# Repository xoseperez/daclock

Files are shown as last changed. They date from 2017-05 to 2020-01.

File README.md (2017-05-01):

# DA CLOCK

This repository contains the schematics and board layouts for Eagle of the different DaClock versions I've done so far.
The common parts between all these versions are: a microcontroller on board with some power management, an RTC and connectors for LED strips or matrices.

Current version is 3.0, based on ESP8266 and DS1337S, also features a buzzer and support for both WS2812 strips/matrices and 5050 "single color" strips.

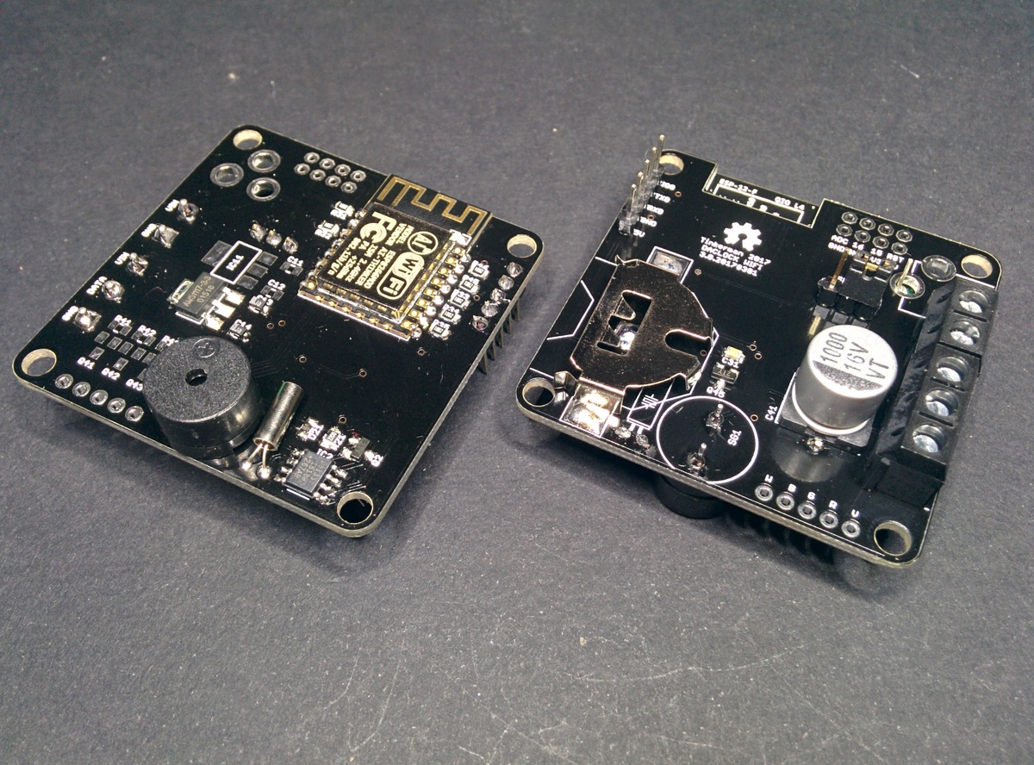
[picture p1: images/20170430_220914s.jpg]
DaClock 3.0


## Versions

### Version 3.0 - WIFI LITE

This is the latest version of the DA CLOCK board, a custom ESP8266-based clock with an RTC, a buzzer and output to handle WS2812 strips.

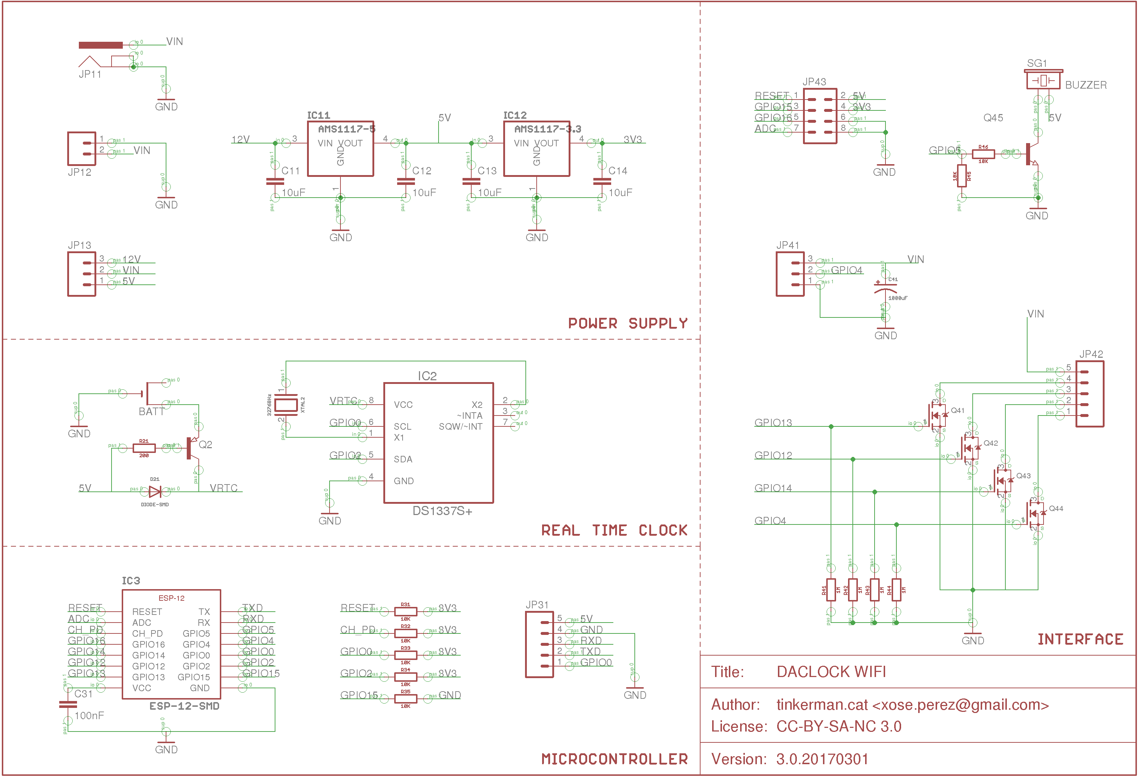
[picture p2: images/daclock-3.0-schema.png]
DaClock 3.0 - schema


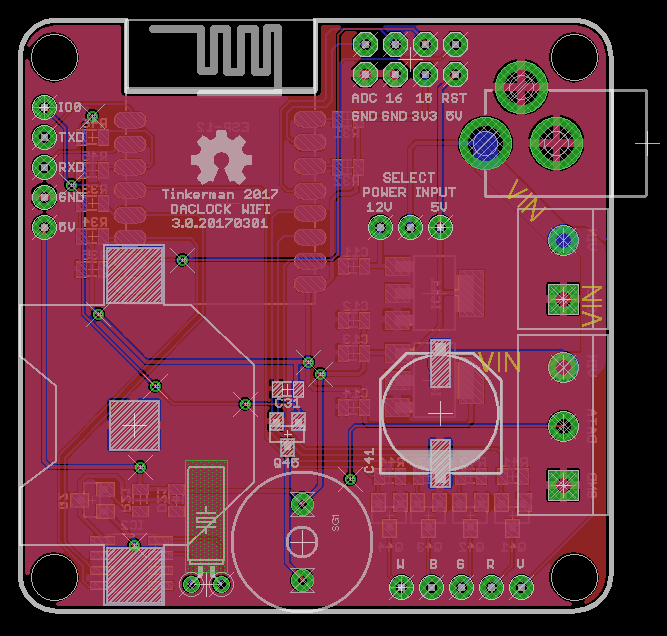
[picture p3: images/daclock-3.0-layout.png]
DaClock 3.0 - layout


#### Bill of materials for a WS2812-based clock

|Item|Buy|Quantity|CPU <sup>units</sup>|Total|
|---|---|---|---|---|
|Tinkerman Da Clock WIFI 3.0|[OSH Park](https://oshpark.com/shared_projects/gDLQyM9I)|1|6.57€ <sup>3</sup>|6.57€|
|Ai-Thinker ESP12F|[Aliexpress](http://s.click.aliexpress.com/e/mUZjemI) / [Ebay](https://rover.ebay.com/rover/1/711-53200-19255-0/1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)|1|2.10€ <sup>5</sup>|2.10€|
|AMS1117-3.3|[Aliexpress](http://s.click.aliexpress.com/e/uj6iuNv) / [Ebay](https://rover.ebay.com/rover/1/711-53200-19255-0/1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)|1|0.03€ <sup>50</sup>|0.03€|
|DS1337S|[Aliexpress](http://s.click.aliexpress.com/e/qbaAUr3) / [Ebay](https://rover.ebay.com/rover/1/711-53200-19255-0/1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)|1|0.62€ <sup>10</sup>|0.62€|
|32KHz crystal|[Aliexpress](http://s.click.aliexpress.com/e/UVrrFmU) / [Ebay](https://rover.ebay.com/rover/1/711-53200-19255-0/1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)|1|0.03€ <sup>50</sup>|0.03€|
|1N4148 SMD Diode|[Aliexpress](http://s.click.aliexpress.com/e/i2nayrB)|1|0.14€ <sup>10</sup>|0.14€|
|Buzzer|[Aliexpress](http://s.click.aliexpress.com/e/VbeAu3z) / [Ebay](https://rover.ebay.com/rover/1/711-53200-19255-0/1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)|1|0.15€<sup>10</sup>|0.15€|
|S8550 SMD NPN transistor|[Aliexpress](http://s.click.aliexpress.com/e/VZ3FYN7)|2|0.02€<sup>100</sup>|0.04€|
|100nF 0805 ceramic capacitor||1|0.01€ <sup>100</sup>|0.01€|
|1uF 10V 0805 tantalum capacitor|[Aliexpress](http://s.click.aliexpress.com/e/ey3ZVn2)|2|0.06€ <sup>50</sup>|0.12€|
|1000uF 16V electrolytic SMD capacitor|[Aliexpress](http://s.click.aliexpress.com/e/MjQ7eMf)|1|0.19€ <sup>10</sup>|0.19€|
|200Ohm 0805 resistor||1|0.01€ <sup>100</sup>|0.01€|
|10KOhm 0805 resistor||7|0.01€ <sup>100</sup>|0.07€|
|2 positions 5mm screw terminal|[Aliexpress](http://s.click.aliexpress.com/e/a2fqnM7)|1|0.06€ <sup>100</sup>|0.06€|
|3 positions 5mm screw terminal|[Aliexpress](http://s.click.aliexpress.com/e/Vjaa2RB)|1|0.07€ <sup>100</sup>|0.07€|
|3 position male header||1|0.01€ <sup>100</sup>|0.01€|
|5 position male header||1|0.01€ <sup>100</sup>|0.01€|
|Jumper||1|0.01€ <sup>100</sup>|0.01€|
|**Total**||||10.25€|

* (units) Minimum quantity for the stated price.
* Prices are based on the cheapest option, usually Aliexpress.
* Check the schematic (image or eagle file) for relation between parts and values.

### Version 2.1 - WIFI

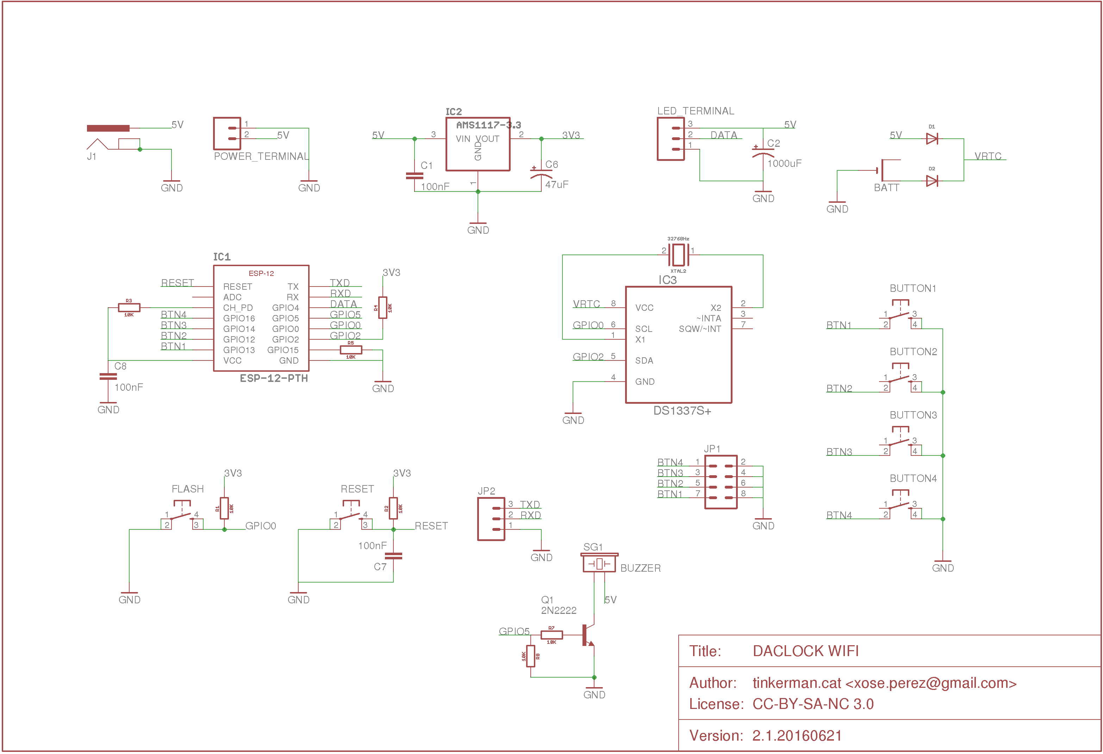
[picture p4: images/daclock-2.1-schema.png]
DaClock 2.1 - schema


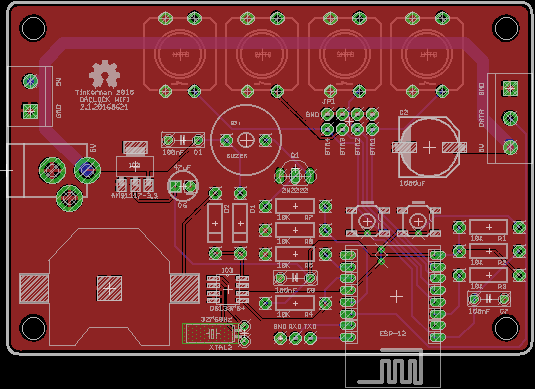
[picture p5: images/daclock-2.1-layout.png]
DaClock 2.1 - layout


### Version 1.2

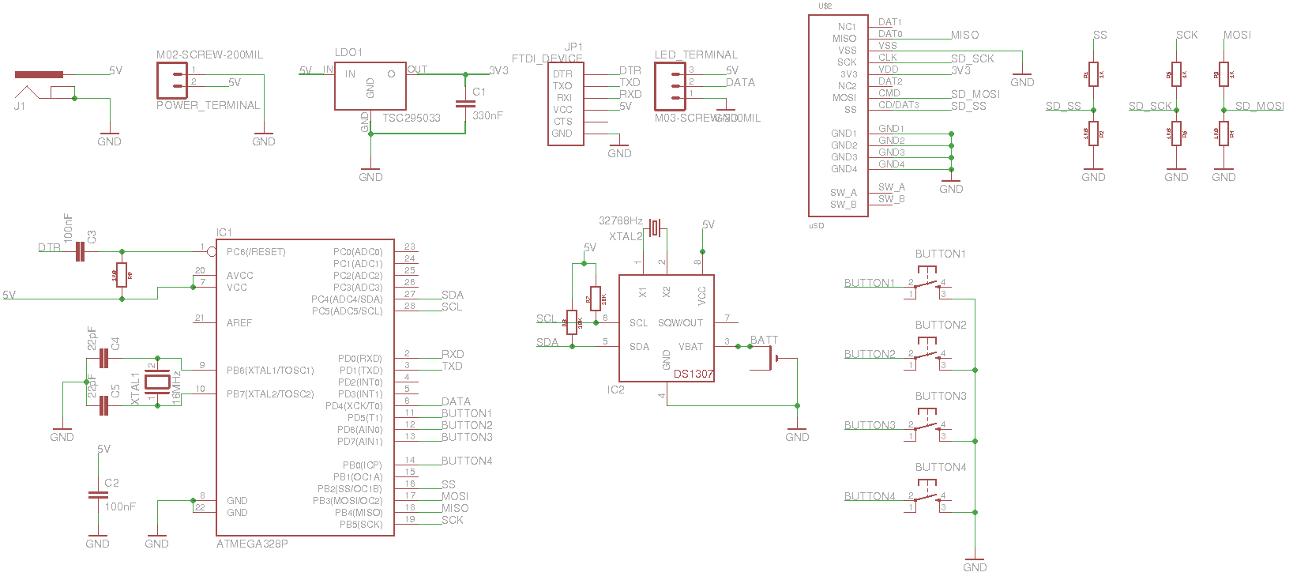
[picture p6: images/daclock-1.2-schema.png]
DaClock 1.2 - schema


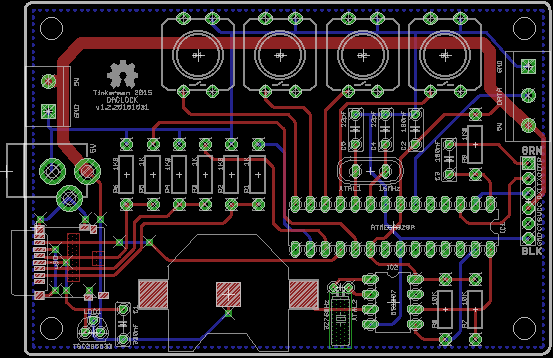
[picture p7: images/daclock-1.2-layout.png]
DaClock 1.2 - layout


## Firmware

* Project [Wordclock](https://bitbucket.org/xoseperez/wordclock) uses version 1.0 of this board (atmega328p based).
- Project [Slices](http://github.com/xoseperez/slices) uses version 3.0 of this board (ESP8266 based).

## Open Hardware

Hardware designs (schematics and CAD) files are licensed under the [Creative Commons Attribution-ShareAlike 3.0 Unported License](http://creativecommons.org/licenses/by-sa/3.0/) and follow the terms of the [OSHW (Open-source hardware) Statement of Principles 1.0.](http://freedomdefined.org/OSHW)

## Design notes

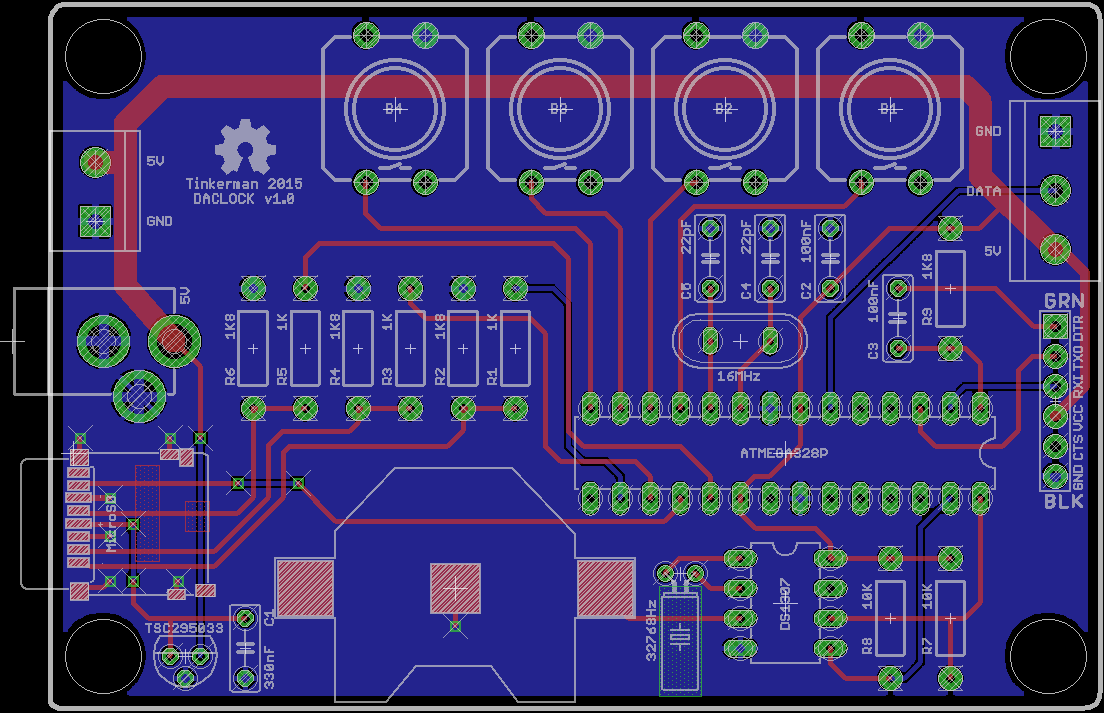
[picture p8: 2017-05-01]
images/daclock-1.0-layout.png

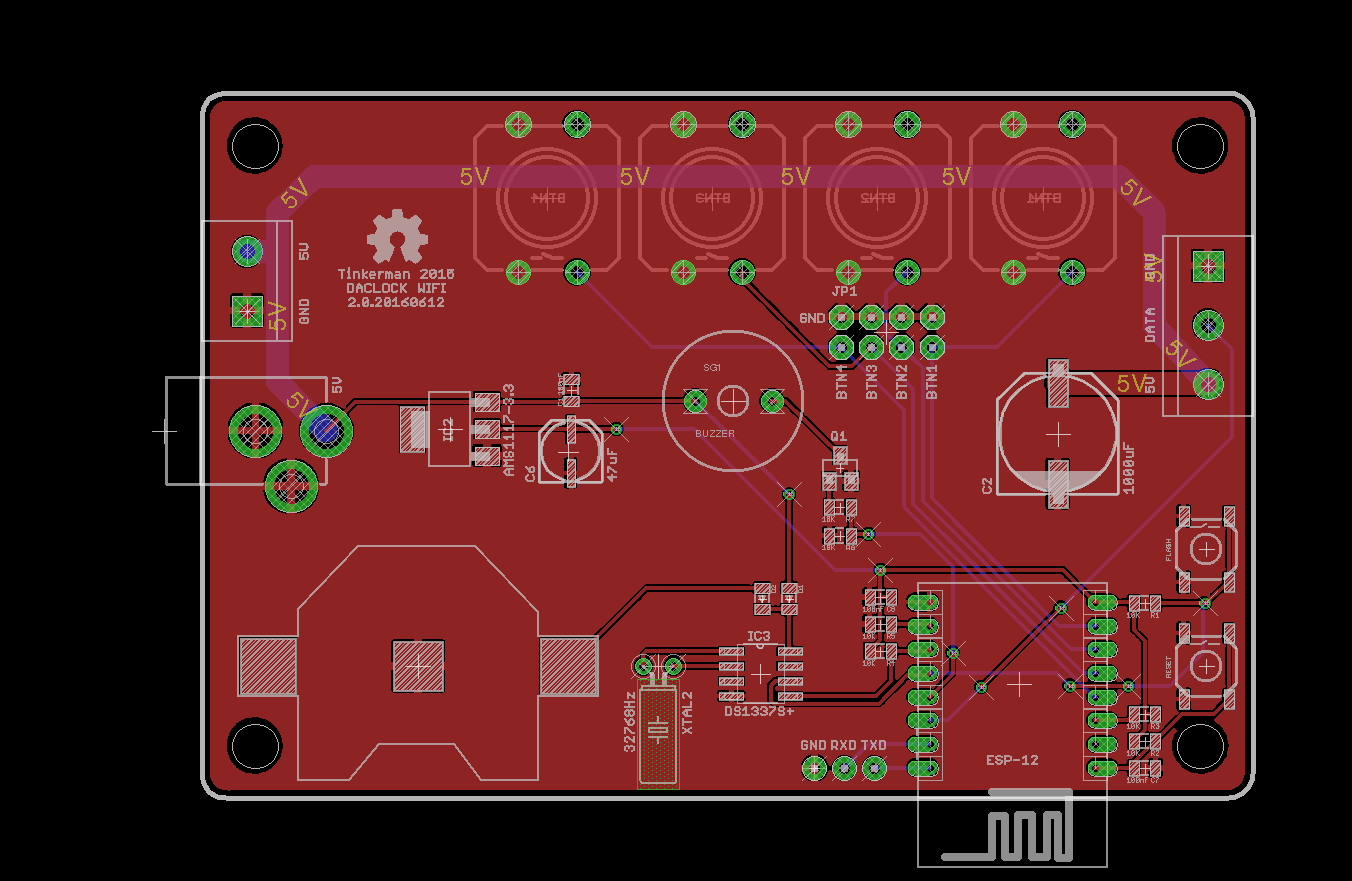
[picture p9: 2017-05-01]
images/daclock-2.0-layout.png

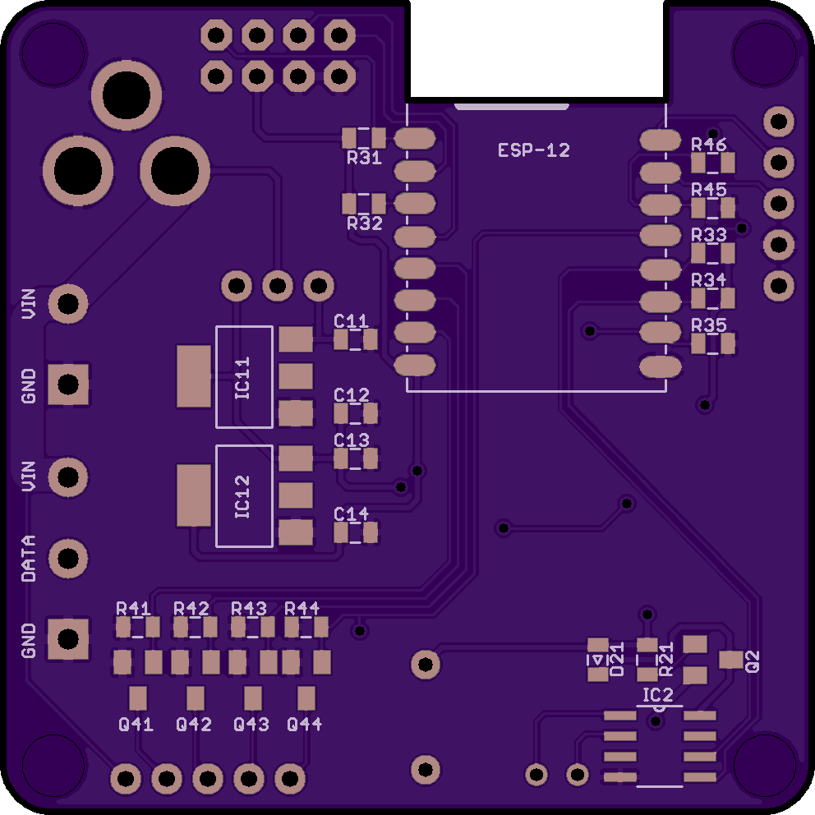
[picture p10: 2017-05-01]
images/daclock-3.0-render-bottom.png

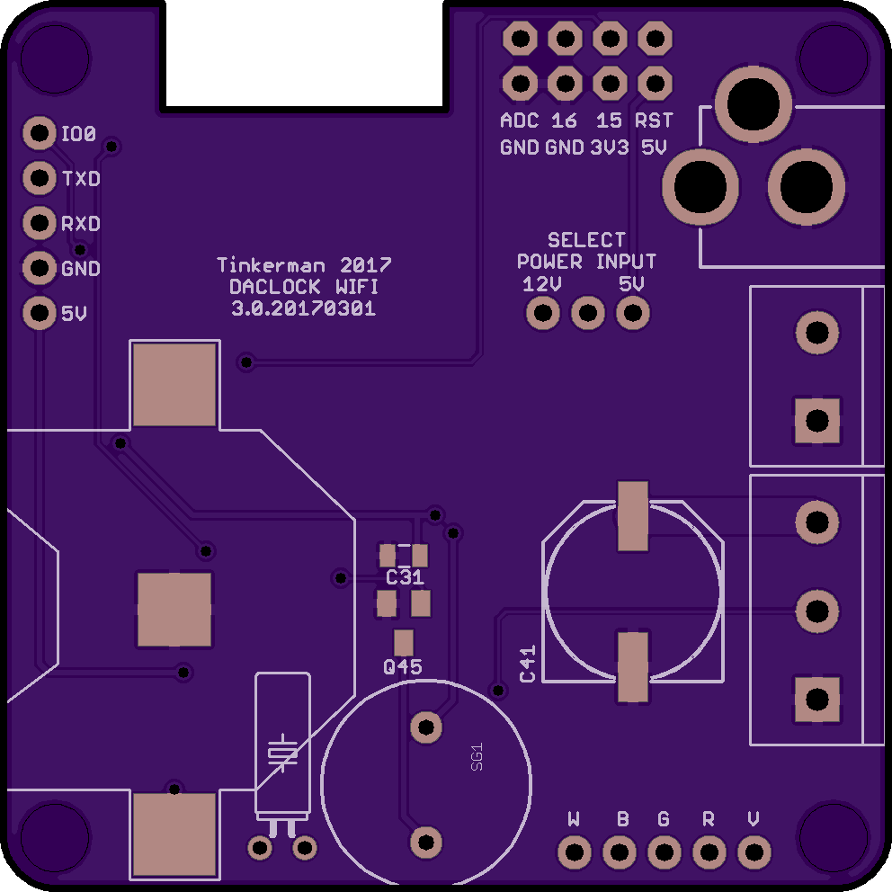
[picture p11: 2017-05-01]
images/daclock-3.0-render-top.png

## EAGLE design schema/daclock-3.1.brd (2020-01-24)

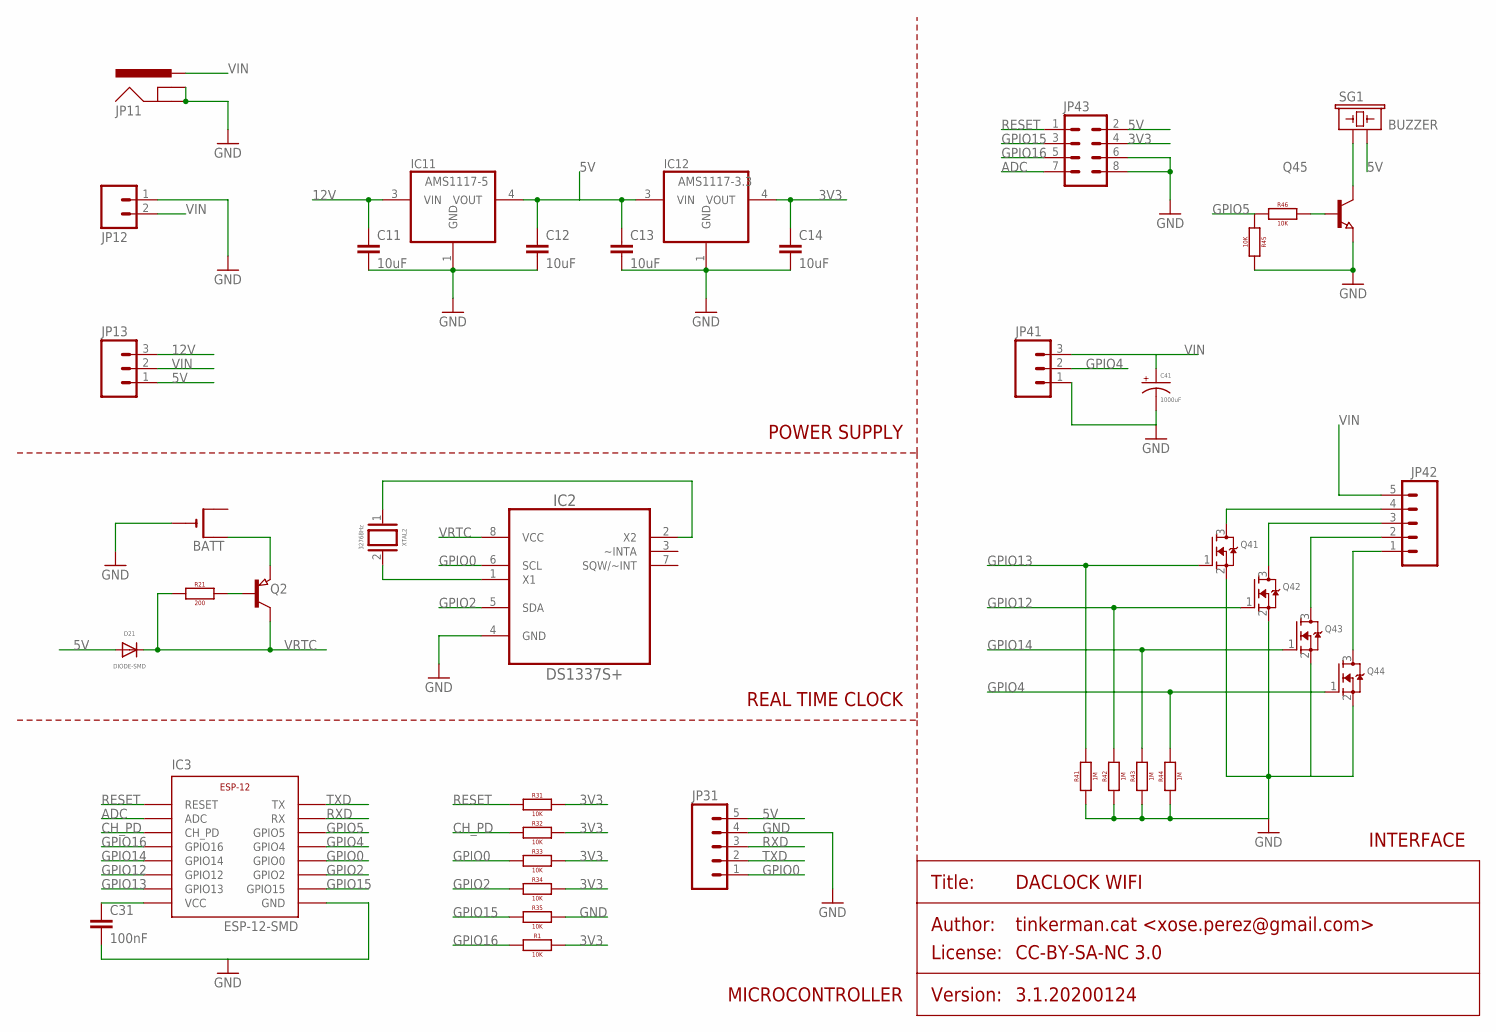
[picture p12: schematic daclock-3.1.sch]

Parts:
BATT: CR2032SMT; CR2032-SMD
C11, C12, C13, C14: 10uF; 0805
C31: 100nF; 0805
C41: 1000uF; PANASONIC_G
D21: DIODE-SMD; 0805_DIODE
IC2: DS1337S+; SOIC127P600X175-8N
IC3: ESP-12-SMD
IC11: AMS1117-5; SOT223
IC12: AMS1117-3.3; SOT223
JP11: POWER_JACKPTH; POWER_JACK_PTH
JP12: M02200MIL; SCREWTERMINAL-200MIL-2
JP13: M03PTH; 1X03
JP31, JP42: M05NO_SILK; 1X05_NO_SILK
JP41: M03200MIL; SCREWTERMINAL-200MIL-3
JP43: M04X2; 2X4
Q2: PNP-TRANSISTOR_SOT23; SOT23
Q41, Q42, Q43, Q44: MOSFET-NREFLOW; SOT23
Q45: NPN-TRANSISTOR_SOT23; SOT23
R1, R31, R32, R33, R34, R35, R45, R46: 10K; 0805
R21: 200; 0805
R41, R42, R43, R44: 1M; 0805
SG1: BUZZER; BUZZER-12MM
XTAL2: 32768Hz; TC38H

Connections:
3V3: C14.1, C31.1, IC3.VCC, IC12.4 (VOUT), JP43.4, R1.2, R31.2, R32.2, R33.2, R34.2
5V: C12.1, C13.1, D21.A, IC11.4 (VOUT), IC12.3 (VIN), JP13.1, JP31.5, JP43.2, SG1.- (2)
12V: C11.1, IC11.3 (VIN), JP13.3
ADC: IC3.ADC, JP43.7
CH_PD: IC3.CH_PD, R32.1
GND: BATT.-, C11.2, C12.2, C13.2, C14.2, C31.2, C41.-, IC2.4 (GND), IC3.GND, IC11.1 (GND), IC12.1 (GND), JP11.GND, JP11.GNDBREAK, JP12.1, JP31.4, JP41.1, JP43.6, JP43.8, Q41.2 (S), Q42.2 (S), Q43.2 (S), Q44.2 (S), Q45.2 (E), R35.2, R41.1, R42.1, R43.1, R44.1, R45.2
GPIO0: IC2.6 (SCL), IC3.GPIO0, JP31.1, R33.1
GPIO2: IC2.5 (SDA), IC3.GPIO2, R34.1
GPIO4: IC3.GPIO4, JP41.2, Q44.1 (G), R44.2
GPIO5: IC3.GPIO5, R45.1, R46.1
GPIO12: IC3.GPIO12, Q42.1 (G), R42.2
GPIO13: IC3.GPIO13, Q41.1 (G), R41.2
GPIO14: IC3.GPIO14, Q43.1 (G), R43.2
GPIO15: IC3.GPIO15, JP43.3, R35.1
GPIO16: IC3.GPIO16, JP43.5, R1.1
unnamed: Q45.1 (B), R46.2
unnamed: IC2.1 (X1), XTAL2.2
unnamed: IC2.2 (X2), XTAL2.1
unnamed: JP42.4, Q41.3 (D)
unnamed: Q2.1 (B), R21.2
unnamed: JP42.3, Q42.3 (D)
unnamed: BATT.+$1 (+), Q2.2 (E)
unnamed: JP42.2, Q43.3 (D)
unnamed: JP42.1, Q44.3 (D)
unnamed: Q45.3 (C), SG1.+ (1)
RESET: IC3.RESET, JP43.1, R31.1
RXD: IC3.RX, JP31.3
TXD: IC3.TX, JP31.2
VIN: C41.+, JP11.PWR, JP12.2, JP13.2, JP41.3, JP42.5
VRTC: D21.C, IC2.8 (VCC), Q2.3 (C), R21.1

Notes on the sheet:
POWER SUPPLY
REAL TIME CLOCK
MICROCONTROLLER
INTERFACE

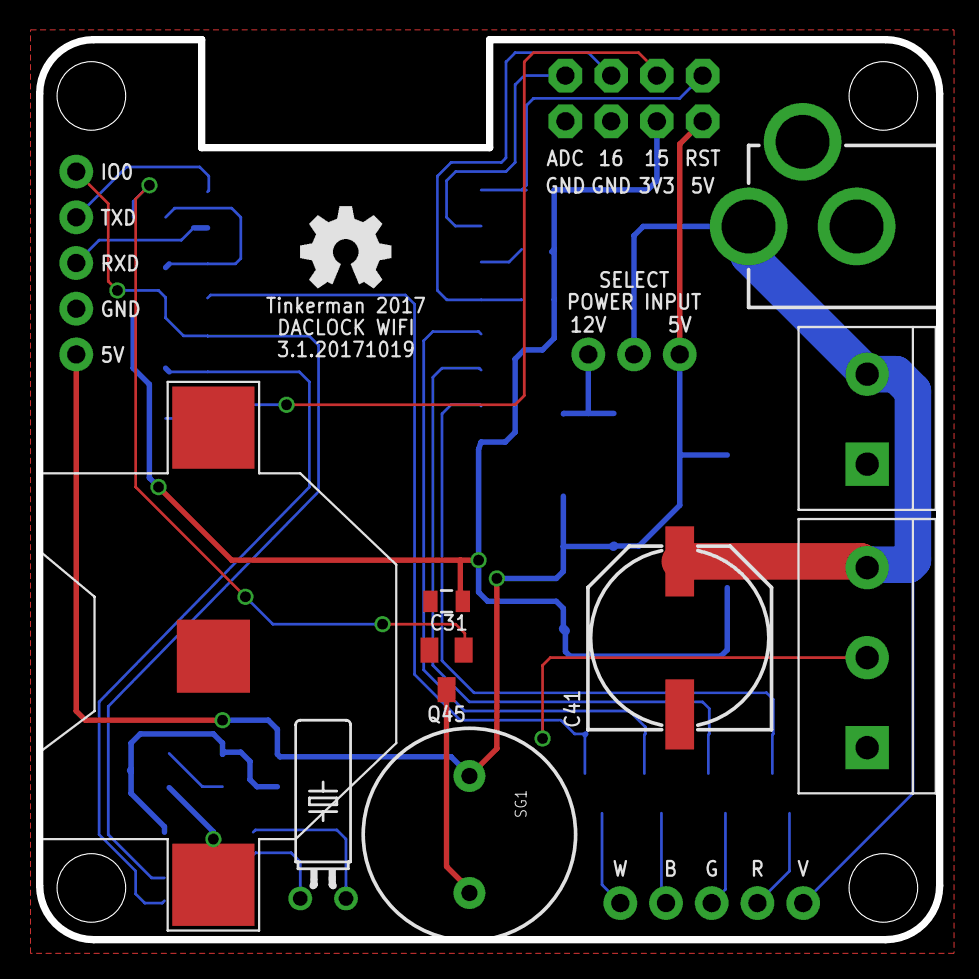
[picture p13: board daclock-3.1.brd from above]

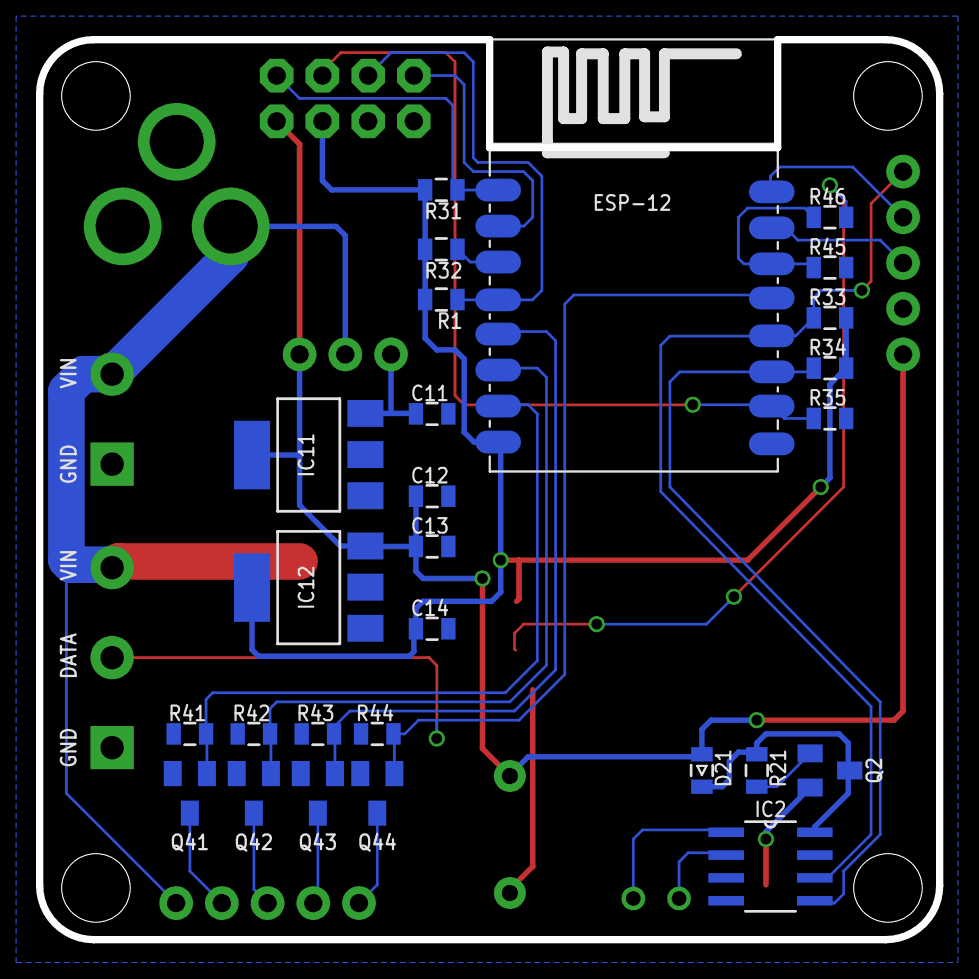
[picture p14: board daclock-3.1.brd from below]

Board: 2 copper layers, 50.0 x 50.0 mm, 40 parts (27 on the bottom side), 30 nets.

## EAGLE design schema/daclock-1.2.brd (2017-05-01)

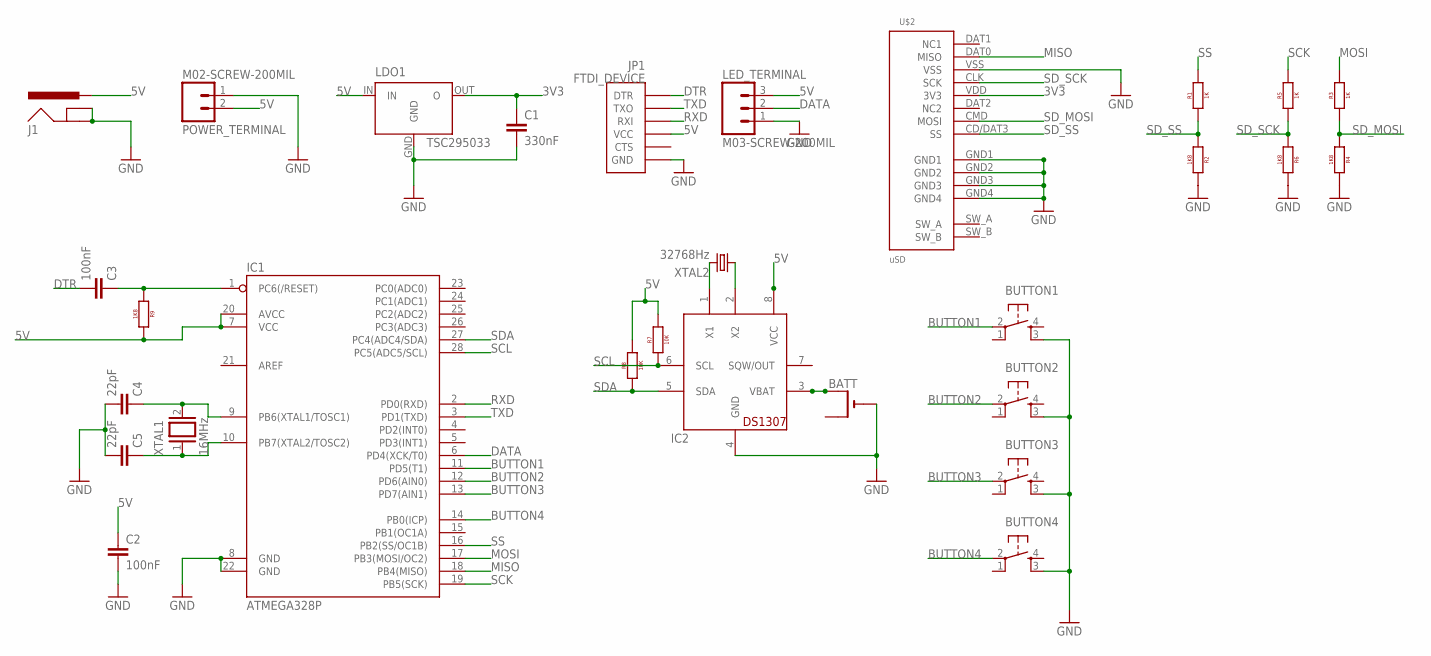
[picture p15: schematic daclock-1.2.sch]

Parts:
BATT: CR2032SMT; CR2032-SMD
BUTTON1: B1; TACTILE_BUTTON
BUTTON2: B2; TACTILE_BUTTON
BUTTON3: B3; TACTILE_BUTTON
BUTTON4: B4; TACTILE_BUTTON
C1: 330nF; C050-025X075
C2, C3: 100nF; C050-025X075
C4, C5: 22pF; C050-025X075
IC1: ATMEGA328P; DIL28-3
IC2: DS1307; DIL08
J1: POWER_JACKPTH; POWER_JACK_PTH
JP1: FTDI_DEVICE; FTDI_DEVICE_SIDE
LDO1: TSC295033; TO92
LED_TERMINAL: M03-SCREW-200MIL; SCREWTERMINAL-200MIL-3
POWER_TERMINAL: M02-SCREW-200MIL; SCREWTERMINAL-200MIL-2
R1, R3, R5: 1K; AXIAL-0.4
R2, R4, R6, R9: 1K8; AXIAL-0.4
R7, R8: 10K; AXIAL-0.4
U$2: uSD; DM3D
XTAL1: 16MHz; QS
XTAL2: 32768Hz; TC38H

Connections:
3V3: C1.1, LDO1.OUT (O), U$2.VDD (3V3)
5V: C2.1, IC1.7 (VCC), IC1.20 (AVCC), IC2.8 (VCC), J1.PWR, JP1.P$4 (VCC), LDO1.IN, LED_TERMINAL.3, POWER_TERMINAL.2, R7.P$2 (2), R8.P$2 (2), R9.P$2 (2)
BUTTON1: BUTTON1.2 (SWA1), IC1.11 (PD5(T1))
BUTTON2: BUTTON2.2 (SWA1), IC1.12 (PD6(AIN0))
BUTTON3: BUTTON3.2 (SWA1), IC1.13 (PD7(AIN1))
BUTTON4: BUTTON4.2 (SWA1), IC1.14 (PB0(ICP))
DATA: IC1.6 (PD4(XCK/T0)), LED_TERMINAL.2
DTR: C3.2, JP1.P$1 (DTR)
GND: BATT.-, BUTTON1.3 (SWB2), BUTTON2.3 (SWB2), BUTTON3.3 (SWB2), BUTTON4.3 (SWB2), C1.2, C2.2, C4.2, C5.2, IC1.8 (GND), IC1.22 (GND), IC2.4 (GND), J1.GND, J1.GNDBREAK, JP1.P$6 (GND), LDO1.GND, LED_TERMINAL.1, POWER_TERMINAL.1, R2.P$2 (2), R4.P$2 (2), R6.P$2 (2), U$2.GND1, U$2.GND2, U$2.GND3, U$2.GND4, U$2.VSS
MISO: IC1.18 (PB4(MISO)), U$2.DAT0 (MISO)
MOSI: IC1.17 (PB3(MOSI/OC2)), R3.P$2 (2)
unnamed: C3.1, IC1.1 (PC6(/RESET)), R9.P$1 (1)
unnamed: C4.1, IC1.9 (PB6(XTAL1/TOSC1)), XTAL1.2
unnamed: C5.1, IC1.10 (PB7(XTAL2/TOSC2)), XTAL1.1
unnamed: BATT.+$1 (+), IC2.3 (VBAT)
unnamed: IC2.1 (X1), XTAL2.2
unnamed: IC2.2 (X2), XTAL2.1
RXD: IC1.2 (PD0(RXD)), JP1.P$3 (RXI)
SCK: IC1.19 (PB5(SCK)), R5.P$2 (2)
SCL: IC1.28 (PC5(ADC5/SCL)), IC2.6 (SCL), R7.P$1 (1)
SDA: IC1.27 (PC4(ADC4/SDA)), IC2.5 (SDA), R8.P$1 (1)
SD_MOSI: R3.P$1 (1), R4.P$1 (1), U$2.CMD (MOSI)
SD_SCK: R5.P$1 (1), R6.P$1 (1), U$2.CLK (SCK)
SD_SS: R1.P$1 (1), R2.P$1 (1), U$2.CD/DAT3 (SS)
SS: IC1.16 (PB2(SS/OC1B)), R1.P$2 (2)
TXD: IC1.3 (PD1(TXD)), JP1.P$2 (TXO)

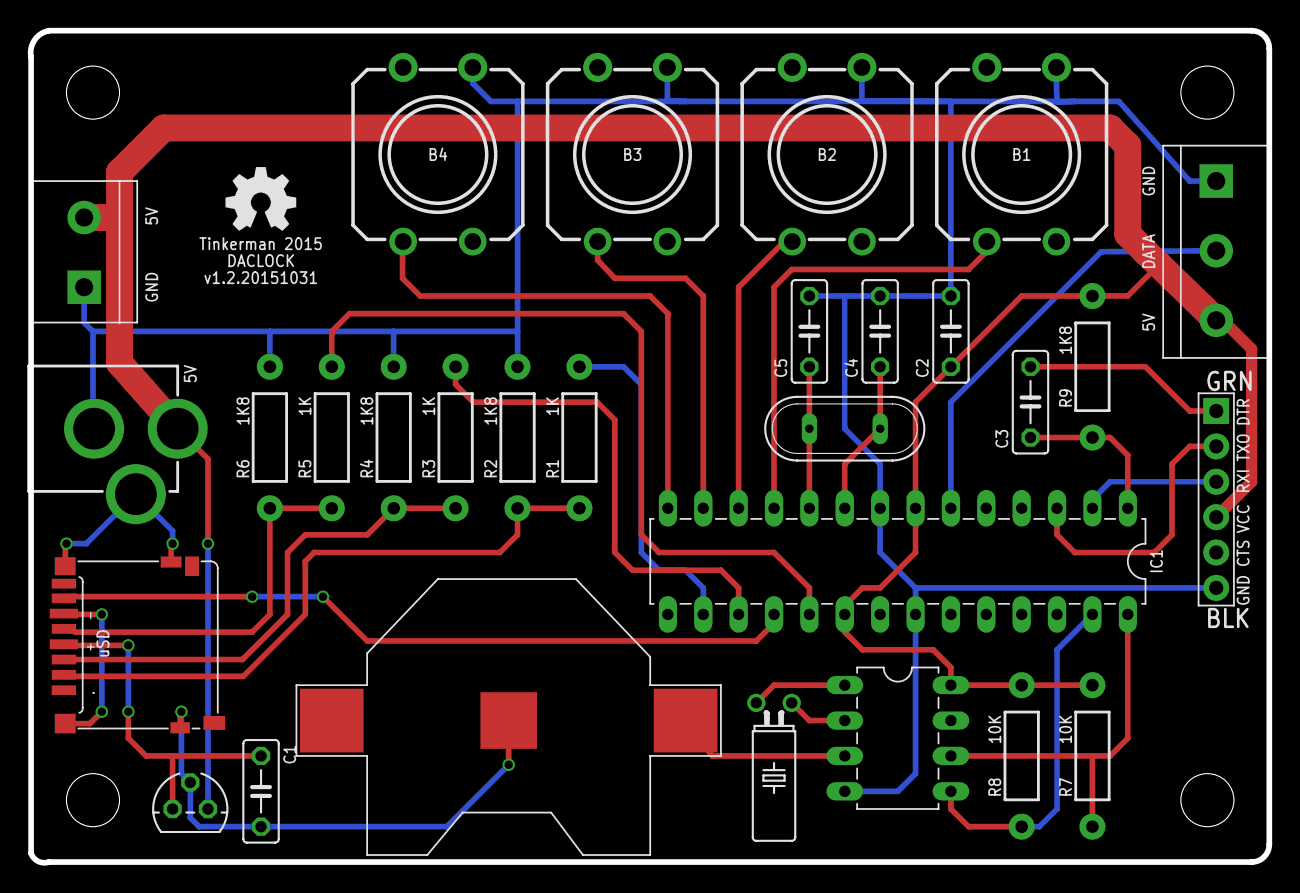
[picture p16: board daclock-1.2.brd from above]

Board: 2 copper layers, 88.9 x 59.7 mm, 29 parts (0 on the bottom side), 26 nets.

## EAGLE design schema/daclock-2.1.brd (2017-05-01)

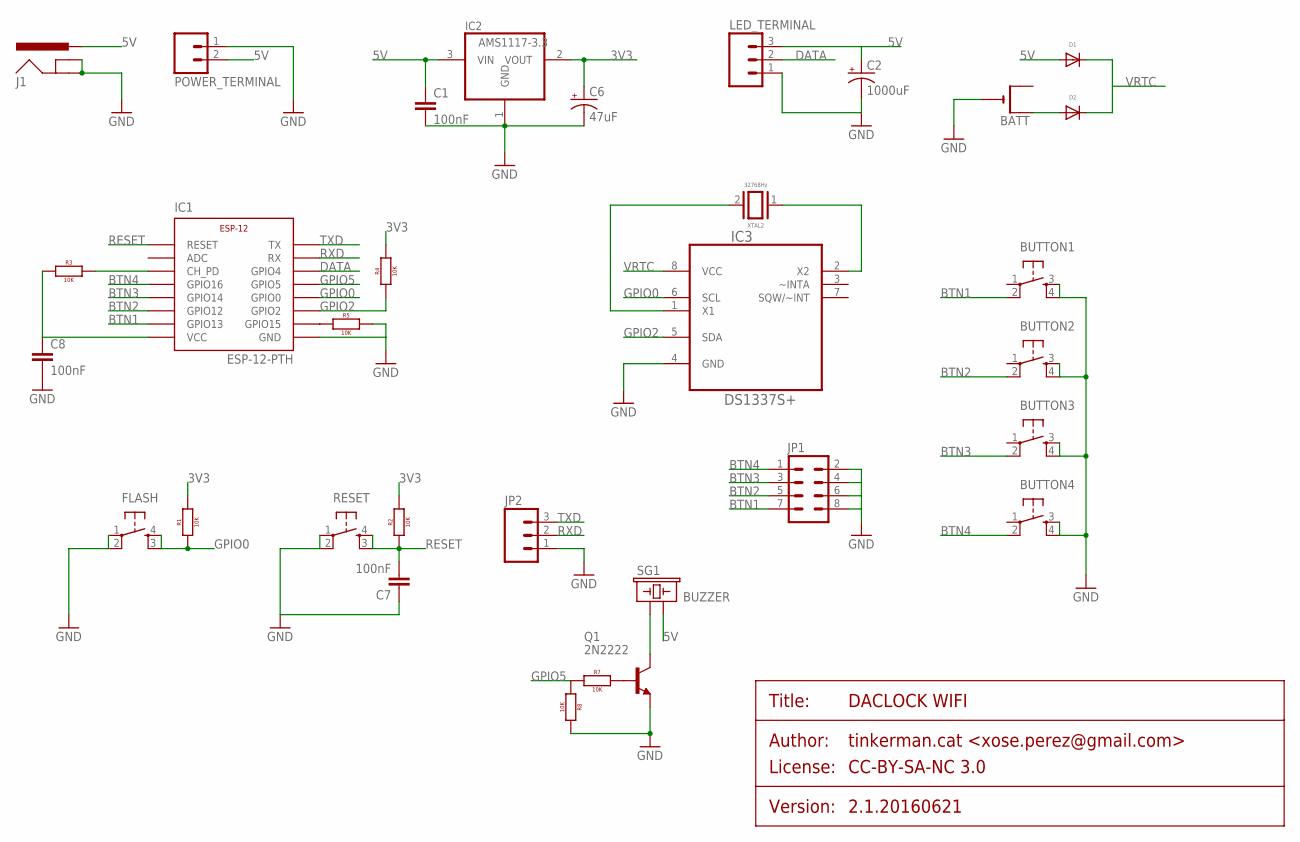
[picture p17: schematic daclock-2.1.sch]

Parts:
BATT: CR2032SMT; CR2032-SMD
BUTTON1: BTN1; TACTILE-BUTTON
BUTTON2: BTN2; TACTILE-BUTTON
BUTTON3: BTN3; TACTILE-BUTTON
BUTTON4: BTN4; TACTILE-BUTTON
C1, C7, C8: 100nF; C050-025X075
C2: 1000uF; PANASONIC_G
C6: 47uF; CPOL-RADIAL-10UF-25V
D1, D2: DIODE-PTH4; AXIAL-0.4-DIODE
FLASH: TACTILE_BUTTON_SMD; TACTILE-BUTTON-SMD
IC1: ESP-12-PTH
IC2: AMS1117-3.3; SOT223
IC3: DS1337S+; SOIC127P600X175-8N
J1: POWER_JACKPTH; POWER_JACK_PTH
JP1: M04X2; 2X4
JP2: M03PTH; 1X03
LED_TERMINAL: M03200MIL; SCREWTERMINAL-200MIL-3
POWER_TERMINAL: M02200MIL; SCREWTERMINAL-200MIL-2
Q1: 2N2222; TO92-EBC-OVAL
R1, R2, R3, R4, R5, R7, R8: 10K; AXIAL-0.4
RESET: TACTILE_BUTTON_SMD; TACTILE-BUTTON-SMD
SG1: BUZZER; BUZZER-12MM
XTAL2: 32768Hz; TC38H

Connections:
3V3: C6.1 (+), C8.1, IC1.VCC, IC2.2 (VOUT), R1.P$2 (2), R2.P$2 (2), R3.P$1 (1), R4.P$2 (2)
5V: C1.1, C2.+, D1.A, IC2.3 (VIN), J1.PWR, LED_TERMINAL.3, POWER_TERMINAL.2, SG1.- (2)
BTN1: BUTTON1.2 (SWB1), IC1.GPIO13, JP1.7
BTN2: BUTTON2.2 (SWB1), IC1.GPIO12, JP1.5
BTN3: BUTTON3.2 (SWB1), IC1.GPIO14, JP1.3
BTN4: BUTTON4.2 (SWB1), IC1.GPIO16, JP1.1
DATA: IC1.GPIO4, LED_TERMINAL.2
GND: BATT.-, BUTTON1.3 (SWA2), BUTTON1.4 (SWB2), BUTTON2.3 (SWA2), BUTTON2.4 (SWB2), BUTTON3.3 (SWA2), BUTTON3.4 (SWB2), BUTTON4.3 (SWA2), BUTTON4.4 (SWB2), C1.2, C2.-, C6.2 (-), C7.1, C8.2, FLASH.1 (SWA1), FLASH.2 (SWB1), IC1.GND, IC2.1 (GND), IC3.4 (GND), J1.GND, J1.GNDBREAK, JP1.2, JP1.4, JP1.6, JP1.8, JP2.1, LED_TERMINAL.1, POWER_TERMINAL.1, Q1.E, R5.P$2 (2), R8.P$2 (2), RESET.1 (SWA1), RESET.2 (SWB1)
GPIO0: FLASH.3 (SWB2), FLASH.4 (SWA2), IC1.GPIO0, IC3.6 (SCL), R1.P$1 (1)
GPIO2: IC1.GPIO2, IC3.5 (SDA), R4.P$1 (1)
GPIO5: IC1.GPIO5, R7.P$1 (1), R8.P$1 (1)
unnamed: Q1.B, R7.P$2 (2)
unnamed: IC3.1 (X1), XTAL2.2
unnamed: IC3.2 (X2), XTAL2.1
unnamed: BATT.+$1 (+), D2.A
unnamed: IC1.CH_PD, R3.P$2 (2)
unnamed: IC1.GPIO15, R5.P$1 (1)
unnamed: Q1.C, SG1.+ (1)
RESET: C7.2, IC1.RESET, R2.P$1 (1), RESET.3 (SWB2), RESET.4 (SWA2)
RXD: IC1.RX, JP2.2
TXD: IC1.TX, JP2.3
VRTC: D1.C, D2.C, IC3.8 (VCC)

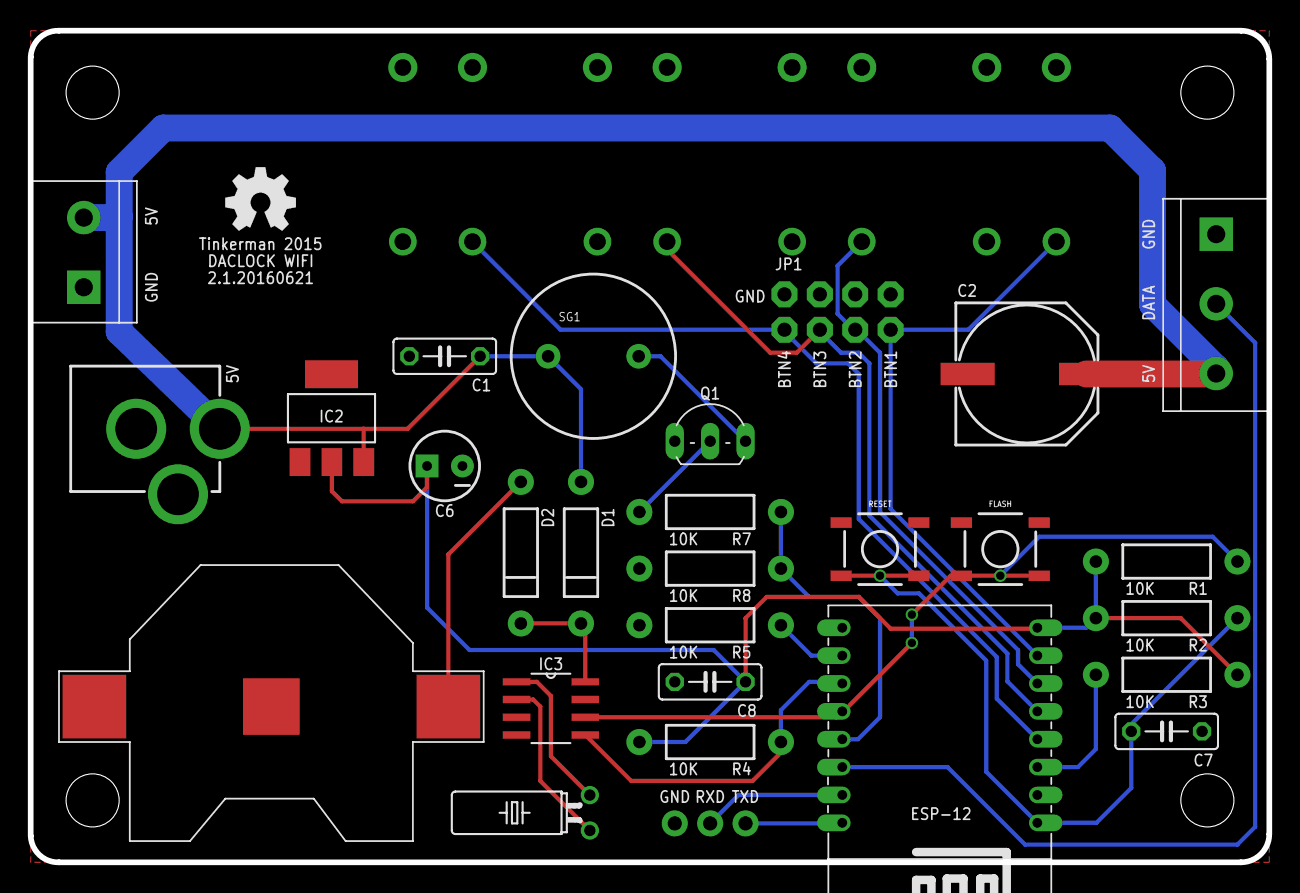
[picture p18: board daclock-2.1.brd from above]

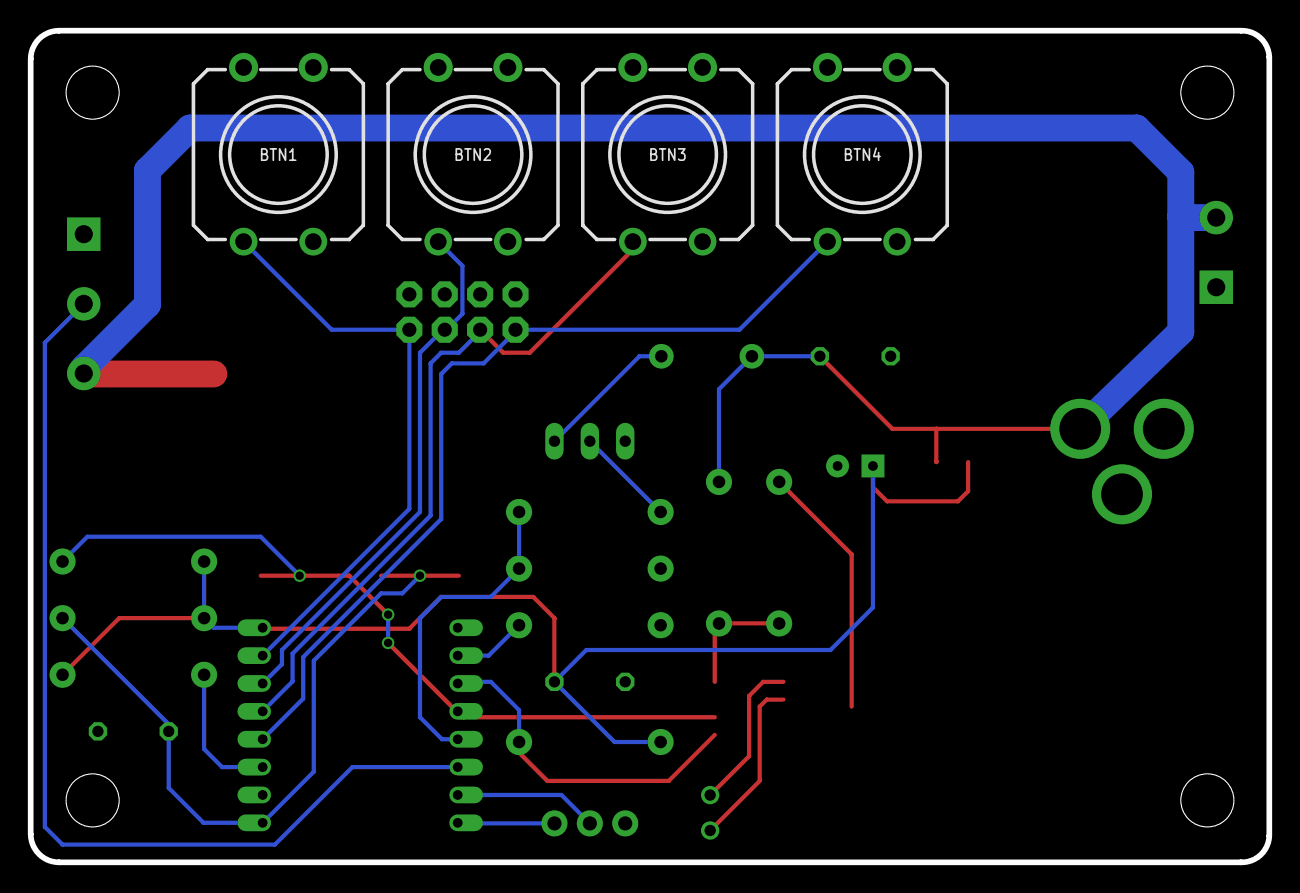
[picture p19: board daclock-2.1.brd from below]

Board: 2 copper layers, 88.9 x 59.7 mm, 32 parts (4 on the bottom side), 22 nets.

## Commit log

2017-05-01 Added image, reverse versions and fix BOM layout
2020-01-24 Update PCB version 3.1
    [daclock-3.1.brd, daclock-3.1.sch]

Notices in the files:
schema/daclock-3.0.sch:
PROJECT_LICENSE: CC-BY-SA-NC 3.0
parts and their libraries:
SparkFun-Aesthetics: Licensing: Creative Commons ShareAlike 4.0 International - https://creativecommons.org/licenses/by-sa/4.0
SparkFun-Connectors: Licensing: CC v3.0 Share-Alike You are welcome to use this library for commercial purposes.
